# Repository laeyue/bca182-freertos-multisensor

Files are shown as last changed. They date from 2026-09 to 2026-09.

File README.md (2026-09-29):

# FreeRTOS STM32 Room Multisensor

## Project Overview

A simulated STM32F103C8 Blue Pill monitors temperature, relative humidity, ambient brightness, and PIR motion. A rotary encoder selects one measurement on an SSD1306 OLED. A 500 Hz PWM buzzer sounds outside the inclusive 18-30 C temperature range. After 15 seconds without PIR activity, the OLED blanks; new motion restores it. The firmware uses STM32Cube HAL and native FreeRTOS APIs, with no Arduino framework or libraries.

The Blue Pill firmware builds and all 15 host logic tests pass. VS Code Wokwi runs verified DHT22 readings, changing LDR values, all four OLED pages, PIR activity/inactivity, and both encoder page sequences with wraparound. At 33.1 C, the OLED displayed ALARM and the Wokwi buzzer activity icon appeared; a PB8 logic-analyzer capture shows approximately 500 Hz PWM, and a recovery capture shows the output returning low after a normal sample. Independent physical sound level and physical-board behavior have not been measured. See [the verification record](docs/verification.md) for evidence and limits.

## Features

- DHT22 temperature and humidity sampling every 2 seconds, with checksum and timeout handling.
- ADC1 light sampling converted to a relative 0-100% brightness indication. It is not calibrated lux.
- PIR motion detection, ACTIVE/INACTIVE state, and 15 second inactivity timeout.
- Four OLED pages with encoder navigation and wraparound.
- High and low temperature alarm with TIM4 PWM output.
- One-slot queues for current readings and display updates, an event group for activity/alarm state, and a mutex for UART diagnostics.

## Learning Objectives

The project demonstrates periodic scheduling, explicit priorities, task states, queue ownership, event signaling, shared UART protection, modular HAL drivers, host unit tests, and PlatformIO static analysis. [The academic report](docs/laboratory-report.pdf) explains the timing and design trade-offs.

## System Architecture

```mermaid
flowchart LR
  DHT[DHT22 PB12] --> STM[STM32F103C8]
  LDR[LDR AO PA0] --> STM
  PIR[PIR PB13] --> STM
  ENC[Encoder PA1/PA2] --> STM
  STM --> OLED[SSD1306 PB6/PB7]
  STM --> BUZ[Buzzer TIM4 CH3 PB8]
  STM --> UART[USART1 PA9 diagnostics]
```

*Figure 1. Peripheral signals and their MCU pins. The editable Wokwi circuit is [diagram.json](diagram.json). See [the verification record](docs/verification.md) for live simulation observations.*

## FreeRTOS Architecture

```mermaid
flowchart LR
  S[SensorTask] -->|SensorData overwrite| DQ[Display sensor queue] --> D[DisplayTask]
  S -->|SensorData overwrite| AQ[Alarm sensor queue] --> A[AlarmTask]
  M[MotionTask] -->|EVENT_MOTION| E[Event group] --> ST[StateTask]
  ST -->|EVENT_ACTIVE| E
  A -->|EVENT_ALARM| E
  M -->|motion boolean| MQ[Motion display queue] --> D
  I[Encoder EXTI] --> EQ[Encoder queue] --> IN[InputTask]
  IN -->|DisplayMode overwrite| PM[Page queue] --> D
  E --> D
  E --> IN
  E --> A
  S & M & ST & IN & A --> U[UART mutex and USART1]
```

*Figure 2. Queue copies keep independent consumers from stealing updates from one another. The event group carries level state and motion signals.*

## Hardware / Simulated Components

STM32 Blue Pill, DHT22, Wokwi photoresistor module, PIR motion sensor, KY-040 rotary encoder, 128x64 SSD1306 I2C OLED, and piezo buzzer. All sensor modules are connected to 3.3 V in the Wokwi diagram.

## Pin Configuration

| Device | Signal | STM32 pin | Driver |
| --- | --- | --- | --- |
| DHT22 | SDA | PB12 | 5.1 kΩ pull-up to 3.3 V; open-drain start, input-pull-up receive |
| LDR | AO | PA0 | ADC1 channel 0 |
| PIR | OUT | PB13 | GPIO input |
| Encoder | CLK / DT | PA1 / PA2 | EXTI1 / GPIO input |
| OLED | SCL / SDA | PB6 / PB7 | I2C1, address 0x3C |
| Buzzer | + | PB8 | TIM4 channel 3 PWM |
| Diagnostics | TX | PA9 | USART1, 115200 baud |

## Task Design

| Task | Priority | Trigger / period | Blocked condition |
| --- | ---: | --- | --- |
| MotionTask | 3 | Every 50 ms | `vTaskDelayUntil()` |
| InputTask | 3 | Encoder EXTI event | Encoder queue receive |
| StateTask | 3 | Motion event or 100 ms timeout | Event-group wait |
| SensorTask | 2 | Every 2 s | `vTaskDelayUntil()` |
| AlarmTask | 2 | Sensor update or 100 ms timeout | Alarm queue receive |
| DisplayTask | 1 | Sensor/page/motion polling, then 100 ms wait | Sensor queue; ACTIVE event while inactive |

Motion, input, and state response have the shortest latency budget. Sampling and alarm processing tolerate the bounded 2-second DHT interval. OLED transfers are slower and can run at priority 1. Each infinite task loop blocks. `vTaskDelayUntil()` anchors repeated wakeups to a fixed schedule so work duration does not accumulate as drift as it would with a plain relative `vTaskDelay()`.

## Inter-Task Communication

`SensorTask` overwrites separate one-element display and alarm queues with `SensorData {temperature, humidity, lightLevel, dhtValid}`. This prevents a consumer from removing a reading needed by another. `MotionTask` sets `EVENT_MOTION` while PIR is high and sends motion changes to the display queue. `StateTask` consumes and clears the motion event, sets or clears `EVENT_ACTIVE`, and owns the activity state. `AlarmTask` owns `EVENT_ALARM`. `InputTask` receives signed encoder directions from the ISR through an eight-item queue and overwrites the selected page queue.

`serialMutex` protects the shared USART1 transmit peripheral. Sensor, motion, input, state, and alarm tasks can log at the same time; without the mutex, byte streams from separate task calls could interleave and corrupt diagnostic lines. The display alone owns I2C1/OLED; no display mutex is needed.

## State Machine

```mermaid
stateDiagram-v2
  [*] --> ACTIVE
  ACTIVE --> INACTIVE: 15 s since last PIR high
  INACTIVE --> ACTIVE: PIR high
  ACTIVE --> ACTIVE: PIR high refreshes timer
  INACTIVE --> INACTIVE: no motion
```

*Figure 3. State transitions. Sensor sampling continues during INACTIVE so a fresh reading is available after reactivation; OLED rendering and the buzzer stop.*

## Repository Structure

`src/` holds task and HAL code, `include/` public firmware headers, `lib/logic/` pure decision logic, `test/` native Unity tests, `docs/` report and verification records, and `tools/` build/report scripts. `diagram.json` and `wokwi.toml` define the simulator circuit and firmware paths.

## Getting Started

Install PlatformIO Core or the VS Code PlatformIO extension, then install Wokwi for VS Code. Open this folder. STM32CubeF1 contains the FreeRTOS kernel used by `tools/freertos.py`; it compiles only the Cortex-M3 port and heap_4 allocator. No Arduino dependency is required.

## Building the Project

```sh
pio run -e bluepill_f103c8
```

The generated firmware is `.pio/build/bluepill_f103c8/firmware.bin`. Tested with PlatformIO Core 6.2.0 and ST STM32 platform 20.0.0. The production build used 21,620 B flash and 12,060 B static RAM; rerun the command for current totals.

## Running the Wokwi Simulation

Build first, then use **Wokwi: Start Simulator** in VS Code. The circuit is in `diagram.json`; the compiled binary and ELF paths are in `wokwi.toml`. Open the DHT22 sliders, LDR lux control, PIR motion popup, and encoder arrows to exercise the scenarios in `docs/verification.md`. Allow 15 seconds after PIR returns low to test inactivity. The buzzer is driven by TIM4 PWM, not a static GPIO high.

## Unit Testing

```sh
pio test -e native
```

The 15 Unity cases cover all five alarm boundaries, four navigation transitions, four state transitions, and two ADC brightness endpoints. The native target tests pure logic without requiring a physical board.

## Static Code Analysis

```sh
pio check -e bluepill_f103c8
```

The latest run reports 16 low-severity C-style-cast findings and no medium or high findings. The casts come from STM32 HAL register or FreeRTOS macro expansions at the project call sites; see the report for details.

## Functional Verification

[The verification record](docs/verification.md) lists FT-01 through FT-10 with stimuli, expected outcomes and actual observations. DHT22, LDR, OLED pages, PIR active/inactive transitions, both encoder page sequences with wraparound, and the high-temperature alarm's OLED/buzzer response passed in Wokwi. PB8 PWM start/recovery is retained as VCD evidence. Independent physical sound level and physical-board behavior remain unmeasured. Reversible no-delay and high-priority MotionTask faults starved lower-priority sensor output; a short UART mutex-bypass run did not reproduce interleaving. No test is marked PASS based only on compilation.

### Wokwi evidence

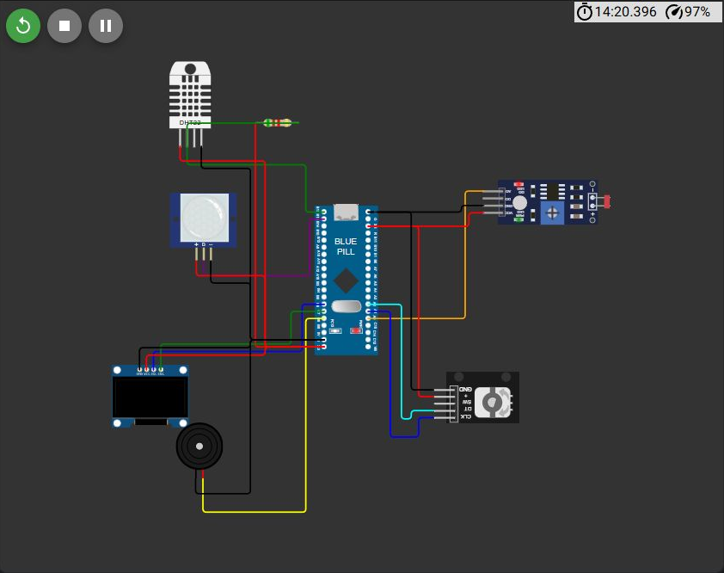
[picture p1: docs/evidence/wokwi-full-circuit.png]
Full Wokwi circuit


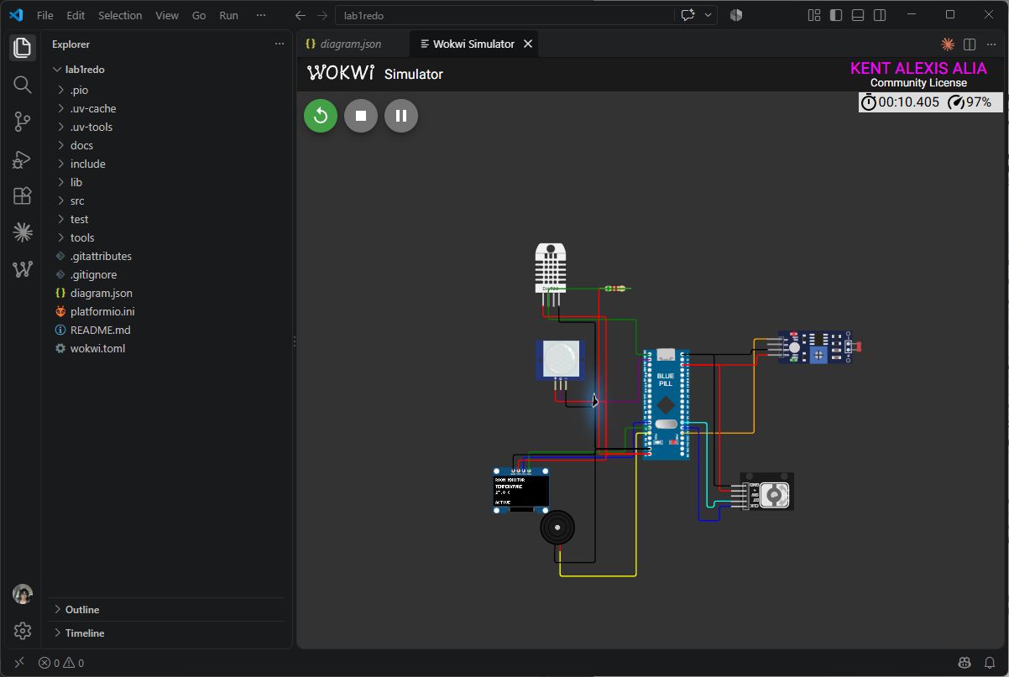
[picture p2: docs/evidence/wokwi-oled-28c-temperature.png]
OLED Temperature page at 27.8 C


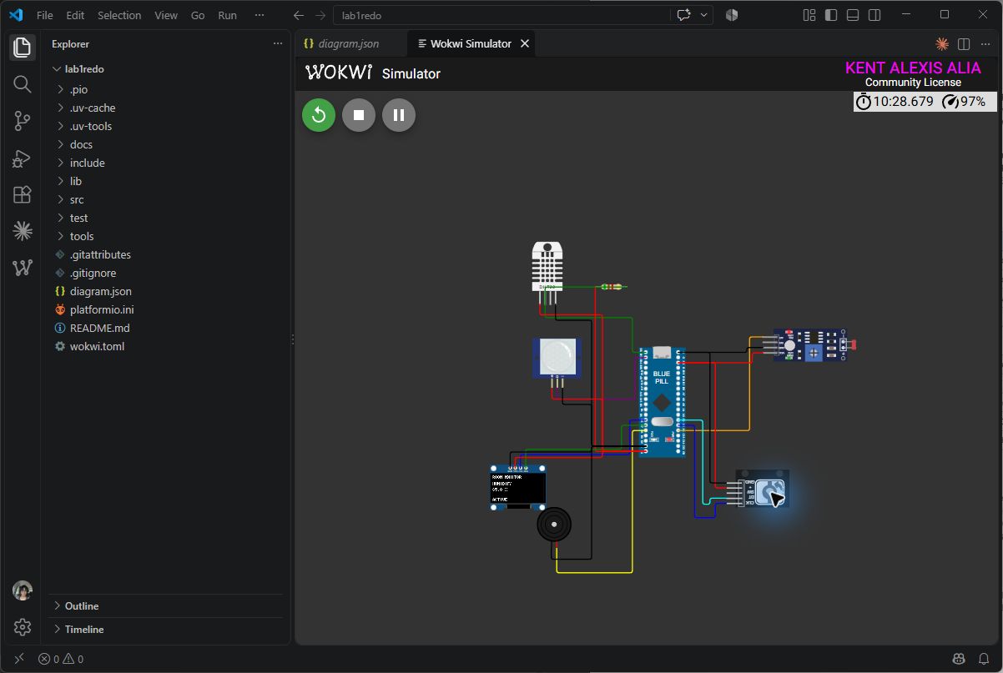
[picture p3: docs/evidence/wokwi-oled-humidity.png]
OLED Humidity page at 65 percent


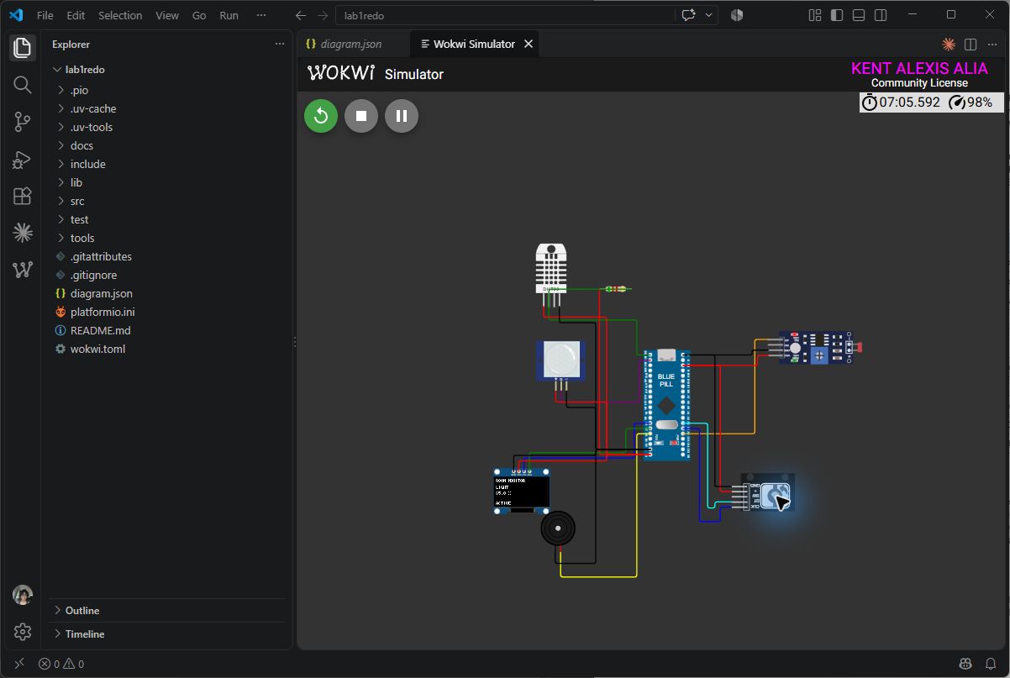
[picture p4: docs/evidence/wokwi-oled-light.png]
OLED Light page


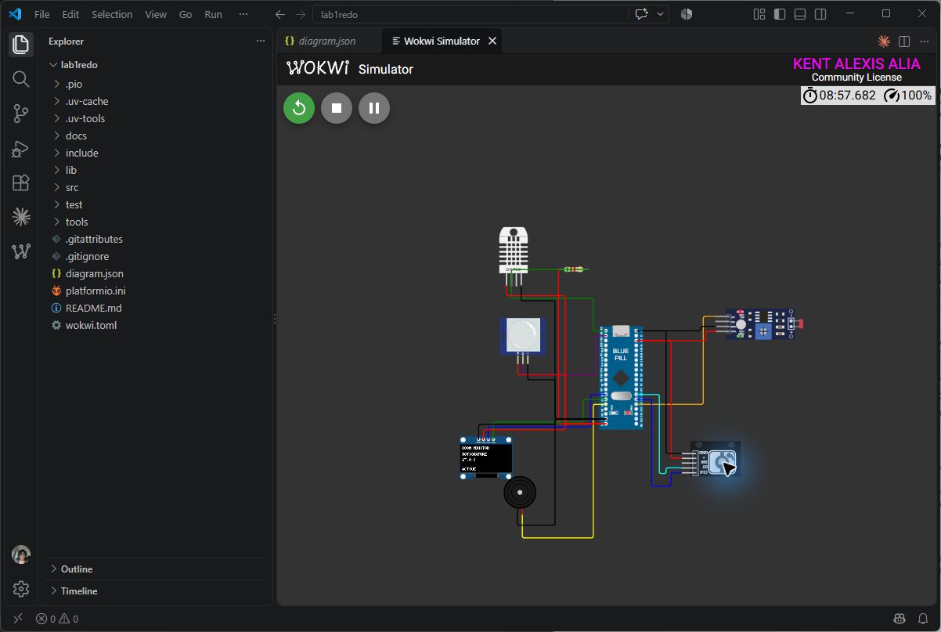
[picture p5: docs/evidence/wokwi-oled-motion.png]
OLED Motion page


[Buzzer high-temperature waveform and recovery](docs/evidence/wokwi-buzzer-alarm-on.vcd) · [PIR high/low trace](docs/evidence/wokwi-pir-cycle.vcd) · [Encoder quadrature trace](docs/evidence/wokwi-input-components.vcd)

## Engineering Decisions

- Two sensor queues give display and alarm independent newest-value mailboxes. A single queue with two consumers would split readings unpredictably.
- The DHT22 transaction samples each data bit 40 us after its rising edge, between the sensor's short zero and long one pulses. The roughly 4 ms transaction runs inside a FreeRTOS critical section, so it temporarily delays lower-priority interrupts; a timer-capture design would scale better on hardware.
- The ADC percentage is inverted because the Wokwi LDR module AO voltage falls as brightness rises. It is a relative indication with no lux claim.
- TIM4 produces an audible 500 Hz square wave; a steady GPIO level would not drive a piezo buzzer properly.
- The alarm is muted in INACTIVE, following the lab's ACTIVE behavior description. Temperature evaluation resumes from current samples when activity returns.

## Limitations

Interactive Wokwi checks cover DHT22 decoding through a 45.8 C input, LDR response, all four OLED pages, task wakeups, PIR high/low and inactivity, both ordered encoder page sequences with wraparound, and the OLED/buzzer high-temperature response. A PB8 VCD proves the buzzer PWM waveform starts at about 500 Hz for a high-temperature sample and stops after a normal sample. No independent physical acoustic level or physical-board behavior has been measured. The no-delay and high-priority fault experiments starved sensor output; the UART mutex-bypass run did not reproduce interleaving. DHT22 sampling masks interrupts for several milliseconds. The inactivity timeout measures from the last observed PIR-high sample; the normal PIR simulation hold is five seconds. No environmental sensor calibration is attempted. DHT errors suppress the alarm rather than sounding a fault tone. Wokwi circuitry does not establish electrical suitability for physical hardware.

## Future Improvements

Capture DHT pulses with a hardware timer input capture, persist configuration in nonvolatile storage, add explicit sensor-fault indication, and measure worst-case task latency and stack high-water marks in Wokwi or on hardware.

## References and Acknowledgments

- [PlatformIO STM32Cube framework documentation](https://docs.platformio.org/en/stable/frameworks/stm32cube.html)
- [Wokwi STM32 Blue Pill support](https://docs.wokwi.com/parts/board-stm32-bluepill)
- [Wokwi simulator configuration](https://docs.wokwi.com/vscode/project-config)
- [Wokwi LDR module behavior](https://docs.wokwi.com/parts/wokwi-photoresistor-sensor)
- BCA182 Laboratory Activity 1, Mindanao State University - Iligan Institute of Technology, September 2026.

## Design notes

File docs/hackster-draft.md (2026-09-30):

# Hackster.io project draft

**Publication state:** Draft prepared; not published.

## Listing details

- **Project name:** Real-Time FreeRTOS Room Multisensor
- **Short description:** An STM32 Blue Pill room monitor built with six FreeRTOS tasks, a DHT22, LDR, PIR sensor, rotary encoder, SSD1306 OLED, and PWM buzzer.
- **Repository:** https://github.com/laeyue/bca182-freertos-multisensor
- **Course attribution:** BCA182, Mindanao State University - Iligan Institute of Technology (MSU-IIT)
- **Team / collaborator field:** Add Prof. Paul Rodolf P. Castor using the matching Hackster profile, as required by the laboratory handout.
- **Tags:** FreeRTOS, STM32, embedded, sensors, Wokwi, PlatformIO
- **License:** The repository does not currently declare a license. Hackster permits publishing without an open-source license; if one is selected, add a matching `LICENSE` file to the repository first.

## Hackster Builder Checklist

The article text below is prepared, but this file is not a Hackster project page. Before publishing, complete the corresponding builder fields and wait until Hackster reports the project as 100% complete:

- Choose a crisp, high-resolution cover image of the finished project. The current simulator and circuit screenshots are evidence images, not a polished cover image.
- Select an accurate difficulty and build time.
- Choose up to three project categories.
- Add the hardware below to Hackster's **Things** list, selecting the matching platform and component entries. Keep software tools in the tools section.
- Add Prof. Paul Rodolf P. Castor as a team member / collaborator using the matching Hackster profile.
- Review the story preview, links, image quality, and publication settings.

The license is optional on Hackster. Decide whether to license the source before publication; do not select a license that does not match the repository.

## Project Overview

This project monitors simulated room temperature, humidity, relative brightness, and motion with an STM32F103C8 Blue Pill. A KY-040 rotary encoder selects one of four pages on an SSD1306 OLED. A 500 Hz buzzer output indicates temperatures outside the 18–30 °C range. After 15 seconds without motion, the display blanks; PIR activity restores the active display.

The project was built for BCA182 Laboratory Activity 1 to demonstrate FreeRTOS task scheduling, inter-task communication, periodic work, and state management on an STM32 target.

## Components and Tools

| Hardware component | Quantity | Use |
| --- | ---: | --- |
| STM32F103C8 Blue Pill | 1 | Main controller |
| DHT22 temperature and humidity sensor | 1 | Temperature and humidity input |
| 5.1 kOhm resistor | 1 | DHT22 data pull-up |
| Photoresistor module (LDR) | 1 | Relative light input |
| PIR motion sensor | 1 | Motion input |
| KY-040 rotary encoder | 1 | Display-page selection |
| SSD1306 I2C OLED | 1 | Measurement and state display |
| Piezo buzzer | 1 | Temperature alarm output |

**Software and tools:** PlatformIO, STM32Cube HAL, FreeRTOS, Unity, and Wokwi.

The full circuit and pin assignment are in the public repository. The circuit uses PB12 for DHT22 data with a 5.1 kOhm pull-up, PA0 for LDR analog output, PB13 for PIR output, PA1/PA2 for encoder CLK/DT, PB6/PB7 for I2C1 OLED, PB8 for TIM4 buzzer PWM, and PA9 for USART1 logging.

Wokwi circuit

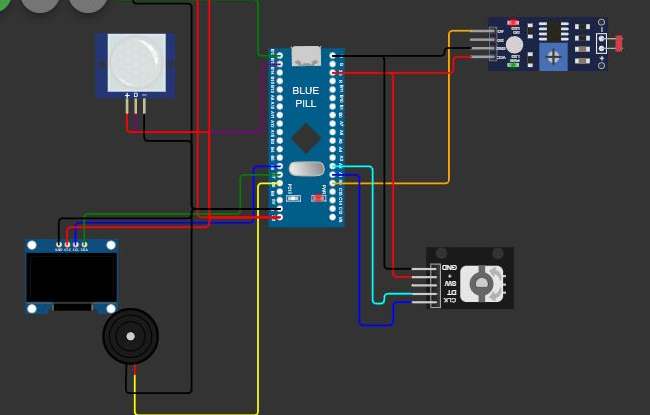
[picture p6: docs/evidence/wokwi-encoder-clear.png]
STM32 Blue Pill, KY-040 encoder, and surrounding wiring


_Wokwi close-up of the STM32 Blue Pill, KY-040 rotary encoder, and surrounding sensor wiring._

## FreeRTOS Architecture

Six tasks divide the work: MotionTask reads PIR state, InputTask handles encoder steps, StateTask owns ACTIVE/INACTIVE state, SensorTask samples DHT22 and LDR, AlarmTask controls the buzzer, and DisplayTask owns the OLED. SensorTask writes the newest sensor data to separate one-item queues for DisplayTask and AlarmTask. The state and alarm event bits live in an event group. A mutex serializes USART1 messages.

The sensor task uses `vTaskDelayUntil()` with a two-second period. The 15-second inactivity timeout is handled by StateTask. Each task blocks on a queue, event, or timed delay between work.

## How It Works

The DHT22 driver releases PB12 into input-pull-up mode and samples each data bit 40 microseconds after its rising edge. This timing separates the sensor's short zero pulse from its longer one pulse. The driver validates the five-byte checksum before publishing a reading. The LDR module is reported as relative brightness, not calibrated lux. Encoder direction is decoded from CLK and DT transitions. DisplayTask renders one selected page. TIM4 channel 3 generates the buzzer waveform at about 500 Hz.

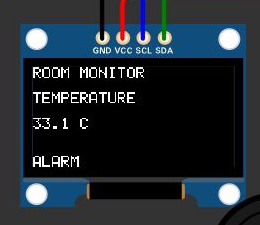
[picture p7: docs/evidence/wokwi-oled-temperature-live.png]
Temperature page


_Live Wokwi OLED view at 33.1 °C with the over-temperature alarm active._

Humidity page

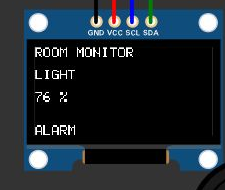
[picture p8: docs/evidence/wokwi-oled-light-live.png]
Light page


_The Light page shows a 76% relative-light reading from the Wokwi photoresistor._

Motion page

## Reproducing the Wokwi Demonstration

1. Clone the [GitHub repository](https://github.com/laeyue/bca182-freertos-multisensor) and open it in VS Code with PlatformIO and Wokwi for VS Code installed.
2. Build the STM32 target with `pio run -e bluepill_f103c8`.
3. Start **Wokwi: Start Simulator**. The circuit is defined in `diagram.json` and the firmware paths are in `wokwi.toml`.
4. Change the DHT22 and photoresistor controls, rotate the encoder in both directions, and trigger the PIR. The [verification record](https://github.com/laeyue/bca182-freertos-multisensor/blob/main/docs/verification.md) lists the observed results and evidence for each functional test.

The Wokwi simulation is the verified target for this project. A physical STM32 board and independent buzzer sound-level measurement were not tested.

## Testing and Verification

The firmware builds for `bluepill_f103c8`. All 15 native Unity tests pass for alarm thresholds, page navigation logic, activity-state transitions, and brightness conversion. PlatformIO static analysis reported zero high and zero medium findings, with 16 low C-style-cast findings at STM32 HAL or FreeRTOS macro call sites.

Live VS Code Wokwi runs showed checksum-valid DHT22 readings, changing LDR output, all four OLED pages, PIR ACTIVE/INACTIVE transitions, and page-change logs for both encoder directions. On 2026-09-30, the full clockwise sequence (Temperature -> Humidity -> Light -> Motion -> Temperature) and reverse sequence (Temperature -> Motion -> Light -> Humidity -> Temperature) were observed while ACTIVE. At 33.1 °C / 66.0%, the OLED showed ALARM and the Wokwi buzzer activity icon appeared; the retained PB8 trace measures about 500 Hz at 50% duty cycle, with a recovery trace returning low after a normal-temperature sample. These are simulator results; no independent physical sound-level measurement or physical-board validation has been made. The test-only PIR hold was restored to its normal five-second value after the run.

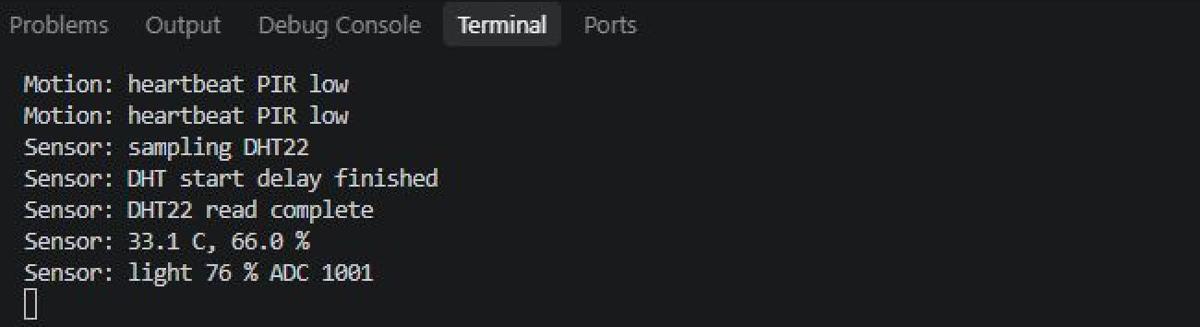
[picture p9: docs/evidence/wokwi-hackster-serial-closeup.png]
Wokwi serial logs from a sensor run


_The serial output records PIR heartbeats, the completed DHT22 read, and the photoresistor ADC reading._

The Wokwi functional checks for encoder wraparound and the high-temperature alarm passed. The independent physical sound level remains unmeasured, and the design has not been validated on physical hardware.

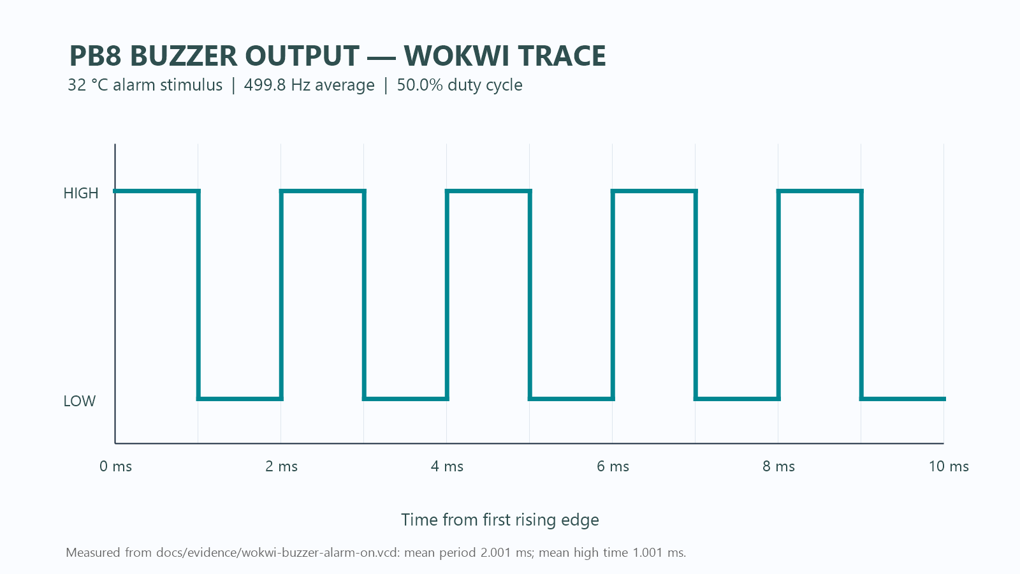
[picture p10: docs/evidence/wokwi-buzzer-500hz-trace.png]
Measured PB8 PWM waveform


_PB8 trace from the 32 °C Wokwi alarm run: 499.8 Hz average and 50.0% duty cycle, measured from the retained VCD capture._

Reversible fault experiments showed that removing MotionTask's blocking delay or raising its priority suppressed sensor output during the observed runs. Bypassing the UART mutex did not reproduce visible line interleaving in the short capture. These are observations from the simulator; they do not replace testing with physical hardware.

The full [functional verification record](https://github.com/laeyue/bca182-freertos-multisensor/blob/main/docs/verification.md) links the screenshots and VCD traces and lists these limits. The public [source repository](https://github.com/laeyue/bca182-freertos-multisensor) includes the circuit, firmware, report, and evidence.

## Challenges and Lessons Learned

A single sensor queue with two consumers would split updates between the display and alarm tasks, so the firmware uses separate one-item mailboxes. The DHT22 needs microsecond timing, and the bit-banged critical section trades interrupt latency for a simpler driver. A steady GPIO level cannot drive a piezo tone; the buzzer needs timer PWM.

## Limitations and Future Improvements

The design has not been validated on a physical board, and no independent acoustic level was measured. Future work could add timer input capture for DHT pulses, calibrated light measurements, measured task latency, and a sensor fault alarm.

## References

BCA182 Laboratory Activity 1 (MSU-IIT, 2026); Aosong AM2302 Technical Manual; STM32CubeF1 documentation and FreeRTOS kernel; PlatformIO STM32Cube documentation; Wokwi component documentation.

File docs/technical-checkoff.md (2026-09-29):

# Technical checkoff notes

Use these notes to explain the design in your own words. The source and actual simulator behavior are the final authority.

1. **Why SensorTask?** DHT22 and ADC acquisition have a 2-second periodic deadline independent of display transfers or encoder events.
2. **Why these priorities?** Motion, encoder and state handling need short response latency (priority 3); sampling and alarm can tolerate the 2-second update cadence (2); the OLED is slower and less urgent (1).
3. **Why `vTaskDelayUntil()`?** It schedules from the previous planned wake time, avoiding cumulative execution-time drift.
4. **What happens during a delay?** The task is Blocked and uses no CPU. At the wake tick it becomes Ready; the scheduler selects it when eligible.
5. **What crosses the sensor queues?** A copied `SensorData`: temperature, humidity, relative light percent and DHT validity.
6. **Why two queues?** DisplayTask and AlarmTask each need the newest sample. Consuming from one shared queue would make one task steal the other's update.
7. **What does the mutex protect?** The shared USART1 transmit operation used by five tasks' diagnostic log calls.
8. **What race can occur?** A task switch during UART output can mix bytes from two messages unless each write holds the mutex.
9. **What are event bits?** MotionTask pulses EVENT_MOTION; StateTask owns EVENT_ACTIVE; AlarmTask owns EVENT_ALARM. Display, input and alarm tasks read relevant level bits.
10. **Who owns the OLED?** DisplayTask alone, so I2C frame writes cannot interleave.
11. **What if a high-priority task never blocks?** It can keep lower-priority sensor, alarm and display tasks Ready indefinitely, causing starvation.
12. **Ready versus Blocked?** Ready can run once selected; Blocked waits for a time, message or event.
13. **What do unit tests verify?** Alarm thresholds including exact boundaries, encoder wraparound, activity-state transitions, and brightness endpoint conversion. A live Wokwi run while ACTIVE showed the clockwise sequence Temperature -> Humidity -> Light -> Motion -> Temperature and the reverse sequence Temperature -> Motion -> Light -> Humidity -> Temperature, with page-change logs.
14. **What did static analysis find?** `pio check` reported 16 low-severity C-style cast findings at HAL/FreeRTOS macro call sites, with no medium or high findings.
15. **What did the buzzer check verify?** At 32 C, PB8 produced approximately 500 Hz PWM; after a 23.5 C sample, PB8 stayed low. In a live 33.1 C Wokwi run, the OLED displayed ALARM and the simulator showed the buzzer activity icon. No independent physical sound-level measurement was made.
16. **What did the fault experiments show?** Removing MotionTask's 50 ms delay caused repeating heartbeats and suppressed sensor output; setting priority 4 with a 1 ms delay also starved sensor output. Bypassing the UART mutex did not visibly corrupt output in the short run, so that race was not reproduced.
17. **What changes on hardware?** Voltage levels, pull-ups, buzzer drive, power supply, sensor calibration, timing margins and EMI need electrical validation. Wokwi models do not establish those properties.

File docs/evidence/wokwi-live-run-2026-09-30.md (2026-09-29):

# Wokwi live verification run — 2026-09-30

This run was performed in the Wokwi VS Code simulator. It records the live
observations made while driving the circuit through the simulator controls.
No screenshot was retained from this session.

## Test setup

- DHT22: 33.1 C and 66.0% humidity for the alarm check.
- PIR `delayTime`: temporarily set to 86,400 seconds because the Wokwi
  simulator fast-forwarded simulated time between manual UI actions.
- After the run, `diagram.json` was restored to DHT22 24 C / 40% and PIR
  `delayTime` 5 seconds.

## Observed results

- Serial output repeatedly showed `Sensor: sampling DHT22`,
  `Sensor: DHT start delay finished`, `Sensor: DHT22 read complete`,
  `Sensor: 33.1 C, 66.0 %`, `Sensor: light 76 % ADC 1001`, and
  `Motion: heartbeat PIR high`.
- While ACTIVE, clockwise encoder steps showed Temperature -> Humidity ->
  Light -> Motion -> Temperature. Counterclockwise steps showed Temperature
  -> Motion -> Light -> Humidity -> Temperature. The serial monitor showed
  `Input: display page changed` during navigation.
- At 33.1 C, the OLED Temperature page showed `ALARM`; Wokwi displayed the
  buzzer activity icon. The retained [PB8 alarm waveform](wokwi-buzzer-alarm-on.vcd)
  separately shows approximately 500 Hz PWM at the high-temperature setting,
  and the [recovery waveform](wokwi-buzzer-recovery.vcd) shows PB8 returning
  low after a normal-temperature sample.

These observations verify the simulated alarm path and both encoder page
sequences. They do not measure physical buzzer loudness or validate the circuit
on a physical board.

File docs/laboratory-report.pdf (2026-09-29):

BCA182 - Laboratory Activity 1 | Page 1

# BCA182 Laboratory Activity 1

Real-Time Multisensor Room Monitoring System

Name: Kent Alexis Alia | Section: B182 | Date: 9/30/26

Status: firmware build, 15 native tests, and static analysis passed. Wokwi verified DHT22 and LDR readings, all four OLED pages, PIR activity/inactivity, clockwise and counterclockwise page wrap, and the high-temperature alarm display/buzzer response. The retained PB8 trace shows PWM start and recovery. Physical sound level and physical-board behavior were not measured. Two reversible scheduling faults starved sensor output; the UART mutex-bypass trial did not reproduce interleaving.

## 1. Problem and Requirements

The device monitors temperature, humidity, relative brightness and motion with a simulated STM32F103C8. A rotary encoder selects one of four OLED pages. A PWM buzzer indicates temperatures strictly below 18 C or strictly above 30 C. A 15-second no-motion interval enters INACTIVE; PIR activity restores ACTIVE. The architecture must use multiple FreeRTOS tasks, queues, a mutex, an event mechanism and periodic execution.

The laboratory handout contains a contradictory statement that the configuration must identify ESP-IDF, adjacent to a STM32Cube example. The STM32 Blue Pill target and all surrounding framework requirements specify STM32Cube, so this project uses framework = stm32cube. Wokwi-supported ADC1, I2C1, USART1, EXTI and TIM2/TIM4 features are used; no Arduino abstraction is included.

## 2. System Architecture and Design

Subsystem | Device / pins | Responsibilities
Sensing | DHT22 PB12; LDR AO PA0 | DHT pulse decoding and checksum; ADC1 relative brightness
Presence / input | PIR PB13; encoder PA1/PA2 | Motion event and page navigation
Output | SSD1306 PB6/PB7; buzzer PB8 | I2C display and TIM4 500 Hz PWM alarm
Diagnostics | USART1 PA9 | Serialized task log output

StateTask owns the ACTIVE/INACTIVE state. On each PIR-high observation it refreshes lastMotion. When elapsed time since that observation reaches 15,000 ms, it clears EVENT_ACTIVE. A new EVENT_MOTION restores ACTIVE. DisplayTask turns the OLED off and blocks on EVENT_ACTIVE while inactive. AlarmTask mutes the buzzer in that state; sensor sampling continues to keep readings fresh.

## 3. FreeRTOS Architecture

Task | Priority | Trigger / period | IPC | Typical blocked condition
MotionTask | 3 | 50 ms | EVENT_MOTION; motion queue | DelayUntil
InputTask | 3 | Encoder EXTI | Encoder and page queues | Queue receive
StateTask | 3 | Motion / 100 ms | Event group | Event wait
SensorTask | 2 | 2 s | Display + alarm queues | DelayUntil
AlarmTask | 2 | Sensor / 100 ms | Alarm queue; EVENT_ALARM | Queue receive
DisplayTask | 1 | Update / 100 ms | Sensor, page, motion queues | Queue or ACTIVE wait

Motion, encoder and state transitions have the tightest response budgets and use priority 3. Two-second sensor sampling and alarm evaluation tolerate priority 2. OLED transfers tolerate additional latency and use priority 1. All loops block or wait, avoiding a continuously ready high-priority task. The only short busy interval is the DHT timing transaction inside a critical section.

SensorTask overwrites two separate single-item SensorData queues. DisplayTask and AlarmTask must both see the newest reading; a single destructive-consumption queue would distribute, rather than broadcast, messages. InputTask consumes signed encoder steps from an ISR queue and writes the current DisplayMode to a mailbox queue. MotionTask sends a separate motion boolean to DisplayTask because the PIR and DHT/ADC have distinct task owners.

EVENT_MOTION is set by MotionTask on PIR-high samples and consumed/cleared by StateTask. EVENT_ACTIVE is set or cleared only by StateTask and read by display, input and alarm tasks. EVENT_ALARM is set or cleared only by AlarmTask and read by DisplayTask. These bits represent actual application events and level state, rather than unused placeholders.

The mutex protects USART1 transmission. SensorTask, MotionTask, InputTask, StateTask and AlarmTask may log concurrently. Without serialization, a task switch between bytes could interleave diagnostic lines. The OLED is single-owner and does not require a mutex.

A Running task currently uses the CPU. A Ready task can run but waits for scheduler selection. A Blocked task waits for time, a queue or an event and consumes no CPU. This application deliberately uses Blocked states. No task is Suspended or Deleted during normal operation; those states mean respectively excluded from scheduling until resumed, and removed with resources eligible for reclamation.

vTaskDelayUntil() computes each wake time from the previous scheduled wake, keeping nominal sensor samples 2 seconds apart. vTaskDelay(2000) would add the execution time of each DHT/ADC cycle to every period, creating cumulative drift.

## 4. Implementation

board.cpp initializes HSI/PLL at 64 MHz, GPIO, ADC1, I2C1, USART1 and two timers. TIM2/DWT timing supports the DHT22 transaction. SensorTask pulls its open-drain data pin low for 2 ms, then samples each data bit 40 us after its rising edge inside a FreeRTOS critical section. This midpoint separates the AM2302 zero pulse (26-28 us high) from its approximately 70 us one pulse. The task validates the checksum and converts tenths to Celsius and relative humidity. Invalid DHT data is shown as SENSOR ERROR and suppresses a false temperature alarm.

The LDR module's AO voltage decreases as simulated illumination increases. The firmware maps the 12-bit ADC code inversely into an approximate 0-100% relative brightness scale; it does not infer calibrated lux. The encoder's CLK falling edge is handled by EXTI1; its DT level determines direction. DisplayTask alone builds a 1 KB page buffer and writes it over I2C1 to the SSD1306. TIM4 channel 3 generates a 500 Hz, 50% duty cycle buzzer waveform.

## 5. Verification and Testing

The bluepill_f103c8 STM32Cube firmware build used 21,620 of 65,536 flash bytes and 12,060 of 20,480 static RAM bytes. All 15 native Unity tests passed: five alarm thresholds, four navigation transitions, four state transitions and two brightness endpoints. Static analysis reported zero high, zero medium and 16 low C-style cast findings at STM32 HAL or FreeRTOS macro call sites. These checks do not test HAL timing or wiring.

Functional tests | Evidence state
DHT22 acquisition | Checksum-valid Wokwi serial reads at 24 C / 40%, 27.8 C / 65%, 32 C / 65%, and 45.8 C / 65%; revised 40 us midpoint decoder
FT-01 to FT-03: OLED sensor pages | PASS: Temperature 27.8 C, Humidity 65.0%, and Light page rendered; corresponding screenshots are in docs/evidence/
FT-04 to FT-05: encoder navigation | PASS: while ACTIVE, Wokwi showed Temperature -> Humidity -> Light -> Motion -> Temperature clockwise and the reverse sequence counterclockwise, with page-change logs
FT-06 to FT-07: buzzer thresholds | PASS in Wokwi: at 33.1 C / 66%, OLED showed ALARM and the simulator buzzer activity icon appeared; retained PB8 trace is about 500 Hz and recovery trace returns low. Physical sound level was not measured
FT-08 to FT-10: motion/inactivity | PASS: PIR high produced Motion: detected and State: ACTIVE; the earlier timeout run showed State: INACTIVE and a blank OLED
Fault experiments | No delay and high-priority MotionTask variants suppressed sensor output; bypassing the UART mutex did not produce visible interleaving in the short run

Separate OLED screenshots show all four pages; LDR output changed from 76% at 501 lux to 97% at 13,183 lux. Checksum-valid DHT samples ranged from 24 C to 45.8 C. At 32 C, the PB8 VCD shows 4,096 transitions at about 500 Hz; after a valid 23.5 C sample it stayed low. PIR activation logged ACTIVE, and a separate timeout test logged INACTIVE with the OLED blank. On 2026-09-30, a live VS Code Wokwi run showed the clockwise page sequence Temperature -> Humidity -> Light -> Motion -> Temperature and the reverse sequence, with InputTask page-change logs. At 33.1 C / 66.0%, serial showed a valid sensor sample, the OLED displayed ALARM, and the Wokwi buzzer activity icon appeared. The temporary test DHT and extended PIR hold settings were restored to defaults after the run. No new screenshot was retained; the text run record and retained traces are in docs/evidence/. Physical sound level and physical-board behavior were not measured. No-delay and high-priority faults suppressed sensor output; the UART mutex-bypass test showed no visible interleaving.

## 6. Static Code Analysis

The latest pio check run passed with zero high, zero medium and 16 low style messages. These C-style-cast reports point to STM32 HAL register or FreeRTOS macro expansions at board.cpp, input.cpp and main.cpp call sites; no high or medium finding was reported.

Finding | Location / cause | Resolution
C-style casts (16) | HAL / FreeRTOS macro expansion | Retained; low-severity macro style

## 7. Engineering Discussion

The STM32F103C8 has only 20 KB RAM. A one-kilobyte static OLED framebuffer, one-slot mailboxes and small task stacks keep static RAM below 60% in the measured build. A queue-per-consumer costs some RAM but avoids lost sensor updates. DHT pulse capture disables interrupts for roughly 4 ms, which can disturb precise task latency; timer input capture would be preferable for a production design. The alarm is muted in INACTIVE according to the stated ACTIVE behavior, but a safety-critical monitor could choose to keep it active instead.

The evidence includes Wokwi checks for DHT22 values through 45.8 C, LDR response, four OLED pages, both encoder page sequences with wraparound, PIR active/inactive transitions, and the 500 Hz buzzer PWM start and recovery, in addition to build, unit tests and static analysis. The 2026-09-30 live run also showed the high-temperature ALARM page and the Wokwi buzzer activity icon. The no-delay and high-priority MotionTask faults suppressed sensor output. The UART mutex-bypass trial showed no visible interleaving, so that race was not reproduced. Physical deployment still needs voltage, pull-up, EMI, timing, acoustic and thermal validation. Sensor calibration and fault-tolerant alarming are outside this laboratory prototype.

## 8. Requirements Traceability

Req. | Implementation | Verification
FR-01 | SensorTask DHT temperature | Valid Wokwi readings observed through 45.8 C; OLED FT-01 pass at 27.8 C
FR-02 | SensorTask DHT humidity | Wokwi serial value and OLED FT-02 pass at 65.0%
FR-03 | SensorTask ADC1 relative light | Changed Wokwi ADC readings and OLED FT-03 pass
FR-04 | MotionTask PIR | PASS: motion detected and ACTIVE serial logs observed; high/low trace captured
FR-05 | DisplayTask OLED | Temperature, Humidity, Light and Motion pages rendered in Wokwi
FR-06 | InputTask encoder | PASS: Wokwi showed ordered page navigation and wrap in both directions while ACTIVE
FR-07 | AlarmTask PWM buzzer | PASS for PB8 PWM start and stop: about 500 Hz at 32 C, low after 23.5 C; no acoustic measurement
FR-08 | StateTask ACTIVE/INACTIVE | PASS: ACTIVE and INACTIVE state logs observed with OLED off/on behavior
FR-09 | StateTask 15 s timeout | Unit timeout and Wokwi INACTIVE observation; FT-09 pass
FR-10 | StateTask PIR reactivation | PASS: PIR trigger after inactivity produced Motion: detected and State: ACTIVE

## 9. Conclusion

The project demonstrates a modular STM32Cube/FreeRTOS design with separate task responsibilities, intentional IPC, time-based state management and deterministic host tests. Wokwi verified DHT22 acquisition up to 45.8 C, LDR response, all four OLED pages, PIR activity/inactivity, both ordered encoder page sequences with wraparound, and the high-temperature OLED ALARM/buzzer response. The fault experiments reproduced starvation when a frequent MotionTask did not block or ran at excessive priority; the short UART mutex-bypass trial did not reproduce a corrupted line. Physical sound level and physical-board behavior remain unmeasured.

## References

BCA182 Laboratory Activity 1 (MSU-IIT, 2026); Aosong AM2302 Technical Manual; PlatformIO STM32Cube documentation; Wokwi STM32 Blue Pill documentation; FreeRTOS kernel source distributed in STM32CubeF1.

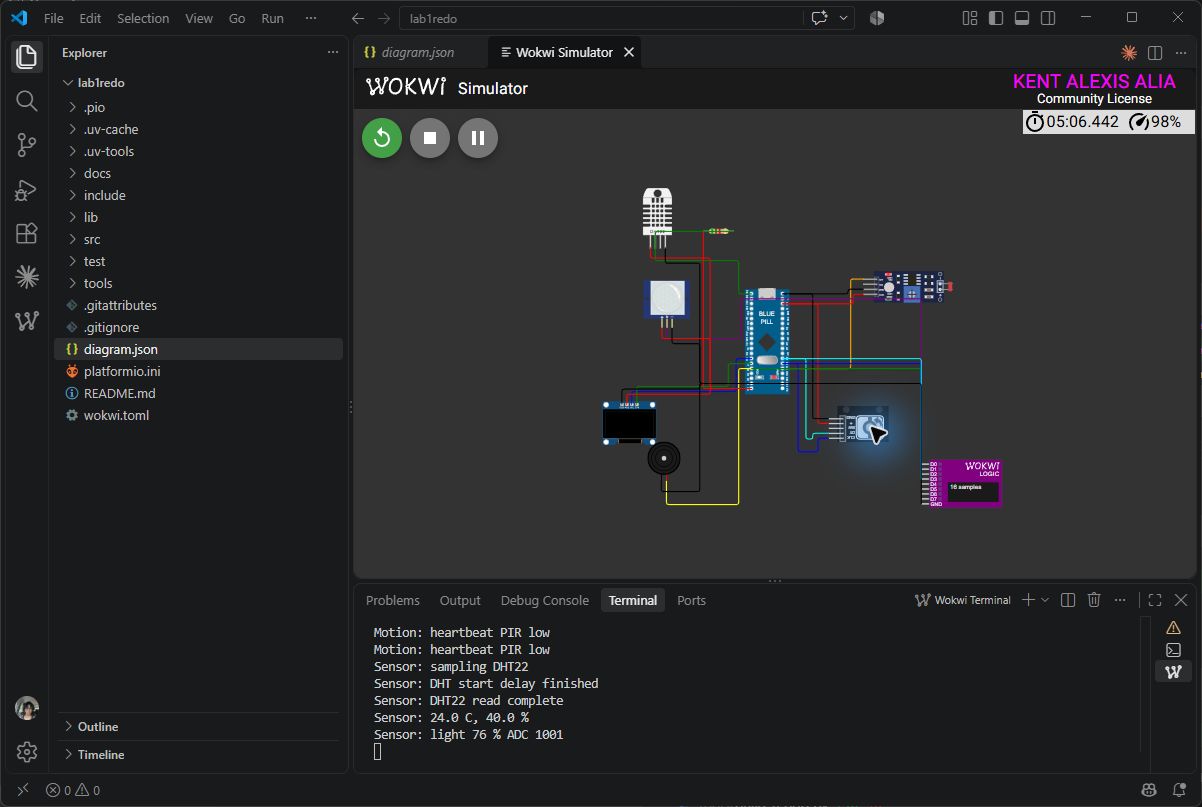
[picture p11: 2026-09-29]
docs/evidence/wokwi-encoder-pulses.png

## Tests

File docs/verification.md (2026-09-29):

# Wokwi functional verification record

Build with `pio run -e bluepill_f103c8`, start Wokwi for VS Code, and record the **observed** OLED/serial/buzzer behavior before assigning PASS or FAIL. Native tests and static analysis do not exercise Wokwi peripherals, so interactive observations are recorded separately below.

## Startup wakeup diagnosis

The original Wokwi run reached `Scheduler running` and
`Sensor: sampling DHT22`, then omitted the DHT start-delay completion and
MotionTask heartbeat. Those messages precede DHT bit decoding, so sensor data
alone could not explain that stall. After the SysTick and PendSV port changes,
a clean Wokwi run reached `Sensor: DHT start delay finished`,
`Sensor: DHT22 read complete`, repeated sensor samples, and MotionTask
heartbeats. One manual restart attempt did not show progress; a rebuild/reload
then produced repeated wakeups. The latest clean image also showed continued
sampling after reload. The startup symptom is considered cleared in the
observed reload run, though restart behavior should be monitored in later runs.

On 2026-09-30, a follow-up live run in VS Code Wokwi again progressed beyond
the earlier stall. The visible serial output included `Sensor: sampling DHT22`,
`Sensor: DHT start delay finished`, `Sensor: DHT22 read complete`,
`Sensor: 33.1 C, 66.0 %`, `Sensor: light 76 % ADC 1001`, and recurring
`Motion: heartbeat PIR high` messages. While ACTIVE, the OLED showed the
clockwise page sequence Temperature -> Humidity -> Light -> Motion ->
Temperature and the reverse sequence Temperature -> Motion -> Light ->
Humidity -> Temperature. `Input: display page changed` appeared as the pages
advanced. At 33.1 C the Temperature page displayed `ALARM`, and the Wokwi
buzzer activity icon was visible. A temporary test setup used DHT22 33.1 C /
66.0% and a 86,400-second PIR hold because Wokwi fast-forwarded simulated time
between manual interactions. The committed diagram was restored to 24 C / 40%
and the normal five-second PIR hold after the run. This live observation was
not saved as a new image; the earlier retained production-run screenshots and
the new text run record are linked below. No independent physical acoustic
measurement was made.

### Static ELF audit

The production ELF places the vector table at `0x08000000`. Its SVC, PendSV,
and SysTick entries resolve to `SVC_Handler` (`0x08001810`),
`PendSV_Handler` (`0x08001870`), and `SysTick_Handler` (`0x08003ef8`). The
disassembly also shows `vTaskDelay()` setting `PENDSVSET`,
`xTaskIncrementTick()` incrementing the tick and moving expired tasks from the
delayed list to the ready list, and PendSV calling `vTaskSwitchContext()`.
These checks rule out a missing or weak exception-vector mapping in the linked
image. They do not show whether PendSV runs in Wokwi or whether UART output is
being lost after the delay.

## DHT22 bus and timing fixes

The failed read was waiting for the sensor's response-high edge. PB12 stayed in
output open-drain mode after the host released the bus, so the STM32F1 internal
pull-up was not enabled. The [AM2302 datasheet](https://files.seeedstudio.com/wiki/Grove-Temperature_and_Humidity_Sensor_Pro/res/AM2302-EN.pdf)
recommends an approximately 5.1 kΩ external pull-up and releasing the bus by
switching the MCU pin to input. The diagram now includes that resistor, and the
driver switches PB12 to input-pull-up for receive and waits two seconds after
power-up before the first sample.

The initial receive implementation classified bits by measuring the high pulse
between two polled GPIO edges and testing whether the result exceeded 50 us.
Because both edge timestamps include polling delay, that decision could move
near the zero/one boundary and produce bad bytes/checksums. The revised decoder
samples the bus 40 us after the rising edge, between the AM2302's short zero
pulse (26-28 us) and long one pulse (about 70 us), then waits for the falling
edge before starting the next bit. A live VS Code Wokwi run produced repeated
checksum-valid `24.0 C, 40.0 %` and `32.0 C, 65.0 %` readings after changing the
DHT controls. No checksum-failure diagnostic appeared in the observed samples.
The timing is based on the [Aosong AM2302 technical manual](https://www.aosong.com/uploadfiles/2025/04/20250417105409216.pdf).

## Buzzer output fix and verification

The high-temperature test initially showed that TIM4 was running while PB8
produced no PWM. The PB8 alternate-function push-pull setup left
`GPIO_InitTypeDef.Speed` at zero; on the STM32F1 this selects the input mode,
so the timer output never reached the pin. `boardInit()` now configures PB8 at
`GPIO_SPEED_FREQ_HIGH` before starting TIM4 channel 3.

With the production firmware, the DHT22 was set to 32.0 C / 65.0%. The live
serial monitor showed that checksum-valid reading, and the logic-analyzer
capture at PB8 contains 4,096 transitions. The measured mean period is about
2.000 ms (approximately 500 Hz) with roughly 50% duty cycle. This proves the
MCU output is producing the configured alarm waveform; it does not constitute
an independent acoustic measurement. The Wokwi buzzer is connected to PB8.

For recovery, the DHT22 was changed live to 23.5 C / 65.0%. The next valid
sample appeared in the serial log, and the recovery VCD ends with PB8 low and
remaining low after the normal-temperature sample. The screenshot and VCD are
stored as `evidence/wokwi-buzzer-recovery.png` and
`evidence/wokwi-buzzer-recovery.vcd`. The no-PWM screenshot records the
pre-fix symptom.

| ID | Stimulus | Expected result | Actual observation | Result |
| --- | --- | --- | --- | --- |
| FT-01 | Set DHT22 to 28 C, select Temperature | OLED shows about 28.0 C within 2 s | DHT control was set to 27.8 C; the Temperature page showed 27.8 C and ACTIVE | PASS |
| FT-02 | Set DHT22 to 65%, select Humidity | OLED shows about 65.0% within 2 s | Humidity page showed 65.0% and ACTIVE; serial output also reported 65.0% | PASS |
| FT-03 | Change LDR lux control, select Light | Relative brightness percentage changes | Light page rendered 97%; serial output changed from 76% (ADC 980 at 501 lux) to 97% (ADC 130 at 13,183 lux) | PASS |
| FT-04 | Rotate encoder clockwise | Temperature -> Humidity -> Light -> Motion -> Temperature | During ACTIVE, the live run showed each page in order and returned to Temperature after the wrap; `Input: display page changed` appeared and the encoder produced CLK/DT pulses | PASS |
| FT-05 | Rotate encoder counterclockwise | Reverse sequence with wraparound | During ACTIVE, the live run showed Temperature -> Motion -> Light -> Humidity -> Temperature, including the reverse wrap; page-change logs appeared | PASS |
| FT-06 | Set DHT22 above 30 C | Buzzer sounds, OLED alarm indicator appears | At 33.1 C / 66.0%, a valid sample was logged and the OLED showed `ALARM`; the Wokwi buzzer activity icon was visible. The retained PB8 VCD measures about 500 Hz at 50% duty at 32 C. Independent physical acoustic level was not measured | PASS (Wokwi) |
| FT-07 | Return DHT22 to 24 C | Buzzer stops within next sensor sample | After changing the live DHT22 to 23.5 C / 65.0%, the next valid sample appeared and the recovery VCD showed PB8 low afterward | PASS |
| FT-08 | Trigger PIR | State log shows ACTIVE and OLED on | During Wokwi motion input, USART1 showed `Motion: detected` and `State: ACTIVE`; the OLED was lit | PASS |
| FT-09 | Wait 15 s after PIR output returns low | State log shows INACTIVE and OLED blanks | `State: INACTIVE` was observed after inactivity, with the OLED blank | PASS |
| FT-10 | Trigger PIR while INACTIVE | OLED restores and state log shows ACTIVE | After inactivity, PIR activation produced `Motion: detected` and `State: ACTIVE`; the OLED returned to its active display | PASS |

## Deliberate FreeRTOS fault experiments

These controlled faults were applied as reversible edits, built and run in Wokwi, then removed. The shipping firmware retains its periodic blocking and UART mutex. Results below describe observed behavior, not predictions.

| Experiment | Temporary change | What to observe | Actual observation | Status |
| --- | --- | --- | --- | --- |
| Remove blocking | Remove `vTaskDelayUntil()` in `MotionTask` | CPU load, lower-priority display/sensor latency, starvation | MotionTask heartbeats repeated continuously; the Wokwi speed indicator fell to 61-67%, and no sensor sample appeared during the observed interval | Observed |
| Raise priority | Set MotionTask priority to 4 and reduce its delay to 1 ms | Scheduling responsiveness of other tasks | The run reached 20 simulated seconds with recurring MotionTask heartbeats but no sensor sample; the simulator ran at about 90-95% speed | Observed starvation |
| Remove mutex | Bypass `serialMutex` in `boardLog` while MotionTask and SensorTask log | Interleaved UART lines | No garbled or interleaved line was visible in the short Wokwi capture; SensorTask and MotionTask messages remained complete. The race was not reproduced at this log rate | Inconclusive |

## Evidence record

1. [Full circuit](evidence/wokwi-full-circuit.png), [final production run](evidence/wokwi-production-final.png), [Temperature](evidence/wokwi-oled-28c-temperature.png), [Humidity](evidence/wokwi-oled-humidity.png), [Light](evidence/wokwi-oled-light.png), and [Motion](evidence/wokwi-oled-motion.png) screenshots record the circuit, stable task wakeups, and page rendering.
2. [Encoder trace](evidence/wokwi-input-components.vcd) contains PA1/PA2 quadrature changes in both directions. [Active encoder screenshot](evidence/wokwi-input-components.png) shows the `Input: display page changed` log while PIR is high. [Encoder pulse screenshot](evidence/wokwi-encoder-pulses.png) records the original pulse check. The 2026-09-30 live run's ordered page sequence is recorded in [the live verification note](evidence/wokwi-live-run-2026-09-30.md).
3. [PIR high/low trace](evidence/wokwi-pir-cycle.vcd) records the sensor output pulse returning low. The live Wokwi serial observation included `Motion: detected` and `State: ACTIVE`; the active encoder screenshot also shows a PIR-high heartbeat during page-change handling.
4. [Buzzer high-temperature waveform](evidence/wokwi-buzzer-alarm-on.vcd) and [test screenshot](evidence/wokwi-buzzer-pwm.png) document the 32 C PWM output; [recovery waveform](evidence/wokwi-buzzer-recovery.vcd) and [screenshot](evidence/wokwi-buzzer-recovery.png) document return to low after the 23.5 C sample. [Pre-fix no-PWM screenshot](evidence/wokwi-buzzer-no-pwm.png) is retained as a diagnostic baseline.
5. Temporary fault observations: [no-blocking run](evidence/experiment-no-blocking.png), [raised-priority run](evidence/experiment-high-priority.png), and [mutex-bypass run](evidence/experiment-no-mutex.png). Production blocking and UART synchronization were restored afterward.

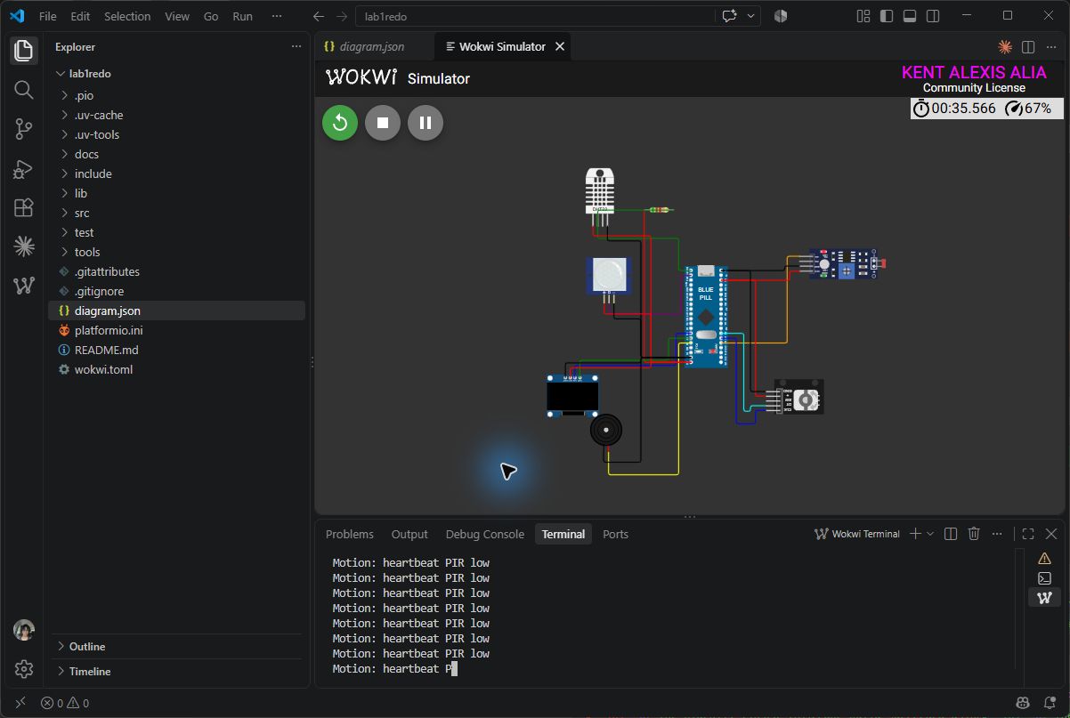
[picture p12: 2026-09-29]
docs/evidence/experiment-no-blocking.png

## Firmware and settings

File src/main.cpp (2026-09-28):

#include "board.h"
#include "rtos_objects.h"
#include "sensors.h"
#include "display.h"
#include "input.h"
#include "motion.h"
#include "alarm.h"
#include "system_state.h"
#include "task.h"

extern "C" void xPortSysTickHandler(void);
extern "C" void vPortSetupTimerInterrupt(void);

namespace {
// SysTick starts before the first task runs. Keep the ISR independent of the
// FreeRTOS API while the kernel is still initializing.
volatile bool schedulerStarted = false;

bool createTask(TaskFunction_t function, const char *name,
                uint16_t stackWords, UBaseType_t priority) {
  if (xTaskCreate(function, name, stackWords, nullptr, priority, nullptr) == pdPASS)
    return true;
  boardLog("Startup failed: cannot create ");
  boardLog(name);
  boardLog("\r\n");
  return false;
}
}

extern "C" void SysTick_Handler(void) {
  HAL_IncTick();
  if (schedulerStarted) xPortSysTickHandler();
}

// FreeRTOS calls this after it has created the idle task and marked the
// scheduler running, with interrupts masked. Start the RTOS tick only here;
// HAL_Init() had already enabled SysTick for HAL timeouts before this point.
extern "C" void vPortSetupTimerInterrupt(void) {
  SysTick->CTRL = 0U;
  SysTick->VAL = 0U;
  SysTick->LOAD = (configCPU_CLOCK_HZ / configTICK_RATE_HZ) - 1UL;
  schedulerStarted = true;
  SysTick->CTRL = SysTick_CTRL_CLKSOURCE_Msk |
                  SysTick_CTRL_TICKINT_Msk |
                  SysTick_CTRL_ENABLE_Msk;
}

extern "C" void vApplicationMallocFailedHook(void) { taskDISABLE_INTERRUPTS(); for (;;) {} }
extern "C" void vApplicationStackOverflowHook(TaskHandle_t, char *) {
  taskDISABLE_INTERRUPTS();
  for (;;) {}
}

extern "C" void HardFault_Handler(void) {
  static const char message[] = "HardFault\r\n";
  HAL_UART_Transmit(&huart1, reinterpret_cast<uint8_t *>(const_cast<char *>(message)),
                    sizeof(message) - 1, 100);
  for (;;) {}
}

void app_main() {
  if (!createRtosObjects()) for (;;) {}
  boardLog(SCB->VTOR == FLASH_BASE ? "Vector table: flash\r\n"
                                   : "Vector table: zero\r\n");
  boardLog("BCA182 FreeRTOS Multisensor System starting...\r\n");
  const bool created =
      createTask(MotionTask, "MotionTask", 160, 3) &&
      createTask(InputTask, "InputTask", 160, 3) &&
      createTask(StateTask, "StateTask", 192, 3) &&
      createTask(SensorTask, "SensorTask", 256, 2) &&
      createTask(AlarmTask, "AlarmTask", 192, 2) &&
      createTask(DisplayTask, "DisplayTask", 320, 1);
  if (!created) for (;;) {}
  boardLog("Tasks created; starting scheduler\r\n");
  vTaskStartScheduler();
  boardLog("Startup failed: scheduler returned\r\n");
  for (;;) {}
}

int main() {
  boardInit();
  app_main();
}

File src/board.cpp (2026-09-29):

#include "board.h"
#include "rtos_objects.h"
#include "task.h"
#include <cstring>

ADC_HandleTypeDef hadc1 = {};
I2C_HandleTypeDef hi2c1 = {};
UART_HandleTypeDef huart1 = {};
TIM_HandleTypeDef htim2 = {};
TIM_HandleTypeDef htim4 = {};

static void initClocks() {
  RCC_OscInitTypeDef oscillator = {};
  oscillator.OscillatorType = RCC_OSCILLATORTYPE_HSI;
  oscillator.HSIState = RCC_HSI_ON;
  oscillator.HSICalibrationValue = RCC_HSICALIBRATION_DEFAULT;
  oscillator.PLL.PLLState = RCC_PLL_ON;
  oscillator.PLL.PLLSource = RCC_PLLSOURCE_HSI_DIV2;
  oscillator.PLL.PLLMUL = RCC_PLL_MUL16;
  if (HAL_RCC_OscConfig(&oscillator) != HAL_OK) while (true) {}

  RCC_ClkInitTypeDef clocks = {};
  clocks.ClockType = RCC_CLOCKTYPE_HCLK | RCC_CLOCKTYPE_SYSCLK |
                     RCC_CLOCKTYPE_PCLK1 | RCC_CLOCKTYPE_PCLK2;
  clocks.SYSCLKSource = RCC_SYSCLKSOURCE_PLLCLK;
  clocks.AHBCLKDivider = RCC_SYSCLK_DIV1;
  clocks.APB1CLKDivider = RCC_HCLK_DIV2;
  clocks.APB2CLKDivider = RCC_HCLK_DIV1;
  if (HAL_RCC_ClockConfig(&clocks, FLASH_LATENCY_2) != HAL_OK) while (true) {}
}

void boardInit() {
  // Wokwi maps the firmware vectors at flash base but does not alias them at 0x0.
  SCB->VTOR = FLASH_BASE;
  __DSB();
  __ISB();
  HAL_Init();
  SCB->VTOR = FLASH_BASE;
  __DSB();
  __ISB();
  initClocks();
  CoreDebug->DEMCR |= CoreDebug_DEMCR_TRCENA_Msk;
  DWT->CYCCNT = 0;
  DWT->CTRL |= DWT_CTRL_CYCCNTENA_Msk;
  __HAL_RCC_GPIOA_CLK_ENABLE();
  __HAL_RCC_GPIOB_CLK_ENABLE();
  __HAL_RCC_AFIO_CLK_ENABLE();
  __HAL_RCC_ADC1_CLK_ENABLE();
  __HAL_RCC_I2C1_CLK_ENABLE();
  __HAL_RCC_USART1_CLK_ENABLE();
  __HAL_RCC_TIM2_CLK_ENABLE();
  __HAL_RCC_TIM4_CLK_ENABLE();

  GPIO_InitTypeDef gpio = {};
  gpio.Pin = DHT_PIN;
  gpio.Mode = GPIO_MODE_INPUT;
  gpio.Pull = GPIO_PULLUP;
  HAL_GPIO_Init(GPIOB, &gpio);
  gpio.Pin = BUZZER_PIN;
  gpio.Mode = GPIO_MODE_AF_PP;
  gpio.Pull = GPIO_NOPULL;
  gpio.Speed = GPIO_SPEED_FREQ_HIGH;
  HAL_GPIO_Init(GPIOB, &gpio);
  gpio.Pin = PIR_PIN;
  gpio.Mode = GPIO_MODE_INPUT;
  gpio.Pull = GPIO_PULLDOWN;
  HAL_GPIO_Init(GPIOB, &gpio);

  gpio.Pin = ENCODER_CLK_PIN;
  gpio.Mode = GPIO_MODE_IT_FALLING;
  gpio.Pull = GPIO_PULLUP;
  HAL_GPIO_Init(GPIOA, &gpio);
  gpio.Pin = ENCODER_DT_PIN;
  gpio.Mode = GPIO_MODE_INPUT;
  HAL_GPIO_Init(GPIOA, &gpio);
  HAL_NVIC_SetPriority(EXTI1_IRQn, 5, 0);
  HAL_NVIC_EnableIRQ(EXTI1_IRQn);

  gpio.Pin = GPIO_PIN_6 | GPIO_PIN_7;
  gpio.Mode = GPIO_MODE_AF_OD;
  gpio.Pull = GPIO_PULLUP;
  gpio.Speed = GPIO_SPEED_FREQ_HIGH;
  HAL_GPIO_Init(GPIOB, &gpio);
  gpio.Pin = GPIO_PIN_9;
  gpio.Mode = GPIO_MODE_AF_PP;
  HAL_GPIO_Init(GPIOA, &gpio);
  gpio.Pin = GPIO_PIN_0;
  gpio.Mode = GPIO_MODE_ANALOG;
  HAL_GPIO_Init(GPIOA, &gpio);

  huart1.Instance = USART1;
  huart1.Init.BaudRate = 115200;
  huart1.Init.WordLength = UART_WORDLENGTH_8B;
  huart1.Init.StopBits = UART_STOPBITS_1;
  huart1.Init.Parity = UART_PARITY_NONE;
  huart1.Init.Mode = UART_MODE_TX;
  huart1.Init.HwFlowCtl = UART_HWCONTROL_NONE;
  huart1.Init.OverSampling = UART_OVERSAMPLING_16;
  if (HAL_UART_Init(&huart1) != HAL_OK) while (true) {}

  hi2c1.Instance = I2C1;
  hi2c1.Init.ClockSpeed = 100000;
  hi2c1.Init.DutyCycle = I2C_DUTYCYCLE_2;
  hi2c1.Init.OwnAddress1 = 0;
  hi2c1.Init.AddressingMode = I2C_ADDRESSINGMODE_7BIT;
  hi2c1.Init.DualAddressMode = I2C_DUALADDRESS_DISABLE;
  hi2c1.Init.OwnAddress2 = 0;
  hi2c1.Init.GeneralCallMode = I2C_GENERALCALL_DISABLE;
  hi2c1.Init.NoStretchMode = I2C_NOSTRETCH_DISABLE;
  if (HAL_I2C_Init(&hi2c1) != HAL_OK) while (true) {}

  hadc1.Instance = ADC1;
  hadc1.Init.ScanConvMode = ADC_SCAN_DISABLE;
  hadc1.Init.ContinuousConvMode = DISABLE;
  hadc1.Init.DiscontinuousConvMode = DISABLE;
  hadc1.Init.ExternalTrigConv = ADC_SOFTWARE_START;
  hadc1.Init.DataAlign = ADC_DATAALIGN_RIGHT;
  hadc1.Init.NbrOfConversion = 1;
  if (HAL_ADC_Init(&hadc1) != HAL_OK) while (true) {}
  ADC_ChannelConfTypeDef channel = {};
  channel.Channel = ADC_CHANNEL_0;
  channel.Rank = ADC_REGULAR_RANK_1;
  channel.SamplingTime = ADC_SAMPLETIME_71CYCLES_5;
  if (HAL_ADC_ConfigChannel(&hadc1, &channel) != HAL_OK) while (true) {}
  HAL_ADCEx_Calibration_Start(&hadc1);

  htim2.Instance = TIM2;
  htim2.Init.Prescaler = (SystemCoreClock / 1000000U) - 1U;
  htim2.Init.CounterMode = TIM_COUNTERMODE_UP;
  htim2.Init.Period = 0xffffU;
  htim2.Init.ClockDivision = TIM_CLOCKDIVISION_DIV1;
  if (HAL_TIM_Base_Init(&htim2) != HAL_OK || HAL_TIM_Base_Start(&htim2) != HAL_OK)
    while (true) {}

  htim4.Instance = TIM4;
  htim4.Init.Prescaler = (SystemCoreClock / 1000000U) - 1U;
  htim4.Init.CounterMode = TIM_COUNTERMODE_UP;
  htim4.Init.Period = 1999U;
  htim4.Init.ClockDivision = TIM_CLOCKDIVISION_DIV1;
  if (HAL_TIM_PWM_Init(&htim4) != HAL_OK) while (true) {}
  TIM_OC_InitTypeDef pulse = {};
  pulse.OCMode = TIM_OCMODE_PWM1;
  pulse.Pulse = 1000U;
  pulse.OCPolarity = TIM_OCPOLARITY_HIGH;
  pulse.OCFastMode = TIM_OCFAST_DISABLE;
  if (HAL_TIM_PWM_ConfigChannel(&htim4, &pulse, TIM_CHANNEL_3) != HAL_OK) while (true) {}
}
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

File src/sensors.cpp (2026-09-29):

#include "sensors.h"
#include "board.h"
#include "rtos_objects.h"
#include "logic.h"
#include "task.h"
#include <cstdio>

static void driveDhtLow() {
  GPIO_InitTypeDef gpio = {};
  gpio.Pin = DHT_PIN;
  gpio.Mode = GPIO_MODE_OUTPUT_OD;
  gpio.Pull = GPIO_NOPULL;
  gpio.Speed = GPIO_SPEED_FREQ_HIGH;
  HAL_GPIO_Init(GPIOB, &gpio);
  HAL_GPIO_WritePin(GPIOB, DHT_PIN, GPIO_PIN_RESET);
}

static void releaseDhtBus() {
  GPIO_InitTypeDef gpio = {};
  gpio.Pin = DHT_PIN;
  gpio.Mode = GPIO_MODE_INPUT;
  gpio.Pull = GPIO_PULLUP;
  HAL_GPIO_Init(GPIOB, &gpio);
}

static bool waitForPin(GPIO_PinState level, uint32_t timeoutUs) {
  const uint32_t start = boardMicros();
  uint32_t spins = 0;
  const uint32_t spinLimit = timeoutUs * 64U;
  while (HAL_GPIO_ReadPin(GPIOB, DHT_PIN) != level) {
    if (static_cast<uint16_t>(boardMicros() - start) > timeoutUs ||
        ++spins >= spinLimit) return false;
  }
  return true;
}

static bool readDht(float &temperature, float &humidity, const char *&failure) {
  uint8_t bytes[5] = {};
  uint8_t decodedOnes = 0;
  uint16_t shortestPulse = UINT16_MAX;
  uint16_t longestPulse = 0;
  driveDhtLow();
  vTaskDelay(pdMS_TO_TICKS(2));
  boardLog("Sensor: DHT start delay finished\r\n");
  taskENTER_CRITICAL();
  releaseDhtBus();
  failure = "response-low";
  bool ok = waitForPin(GPIO_PIN_RESET, 120);
  if (ok) {
    failure = "response-high";
    ok = waitForPin(GPIO_PIN_SET, 120);
  }
  if (ok) {
    failure = "first-data-low";
    ok = waitForPin(GPIO_PIN_RESET, 120);
  }
  for (int bit = 0; bit < 40 && ok; ++bit) {
    failure = "data-bit-low";
    ok = waitForPin(GPIO_PIN_SET, 90);
    if (!ok) break;
    const uint32_t highStart = boardMicros();
    // Sample between the AM2302's 26-28 us zero pulse and ~70 us one pulse.
    // Sampling at a fixed midpoint avoids classifying bits from two polled
    // edge timestamps, whose loop jitter can skew a measured pulse width.
    uint32_t sampleSpins = 0;
    while (static_cast<uint32_t>(boardMicros() - highStart) < 40U) {
      if (++sampleSpins >= 40U * 64U) {
        failure = "data-bit-sample";
        ok = false;
        break;
      }
    }
    if (!ok) break;
    const bool decodedOne = HAL_GPIO_ReadPin(GPIOB, DHT_PIN) == GPIO_PIN_SET;
    failure = "data-bit-high";
    ok = waitForPin(GPIO_PIN_RESET, 100);
    if (!ok) break;
    const uint16_t pulseWidth = static_cast<uint16_t>(boardMicros() - highStart);
    if (pulseWidth < shortestPulse) shortestPulse = pulseWidth;
    if (pulseWidth > longestPulse) longestPulse = pulseWidth;
    if (decodedOne) ++decodedOnes;
    bytes[bit / 8] = static_cast<uint8_t>((bytes[bit / 8] << 1) | (decodedOne ? 1U : 0U));
  }
  taskEXIT_CRITICAL();
  if (!ok) return false;
  failure = "checksum";
  const uint8_t checksum = static_cast<uint8_t>(bytes[0] + bytes[1] + bytes[2] + bytes[3]);
  if (checksum != bytes[4]) {
    char line[128];
    std::snprintf(line, sizeof(line),
                  "Sensor: DHT checksum mismatch sum %02X got %02X, data %02X %02X %02X %02X, bits %u, pulse %u-%u us\r\n",
                  static_cast<unsigned int>(checksum), static_cast<unsigned int>(bytes[4]),
                  static_cast<unsigned int>(bytes[0]), static_cast<unsigned int>(bytes[1]),
                  static_cast<unsigned int>(bytes[2]), static_cast<unsigned int>(bytes[3]),
                  static_cast<unsigned int>(decodedOnes), static_cast<unsigned int>(shortestPulse),
                  static_cast<unsigned int>(longestPulse));
    boardLog(line);
    return false;
  }
  const uint16_t rawHumidity = static_cast<uint16_t>((bytes[0] << 8) | bytes[1]);
  const uint16_t rawTemperature = static_cast<uint16_t>(((bytes[2] & 0x7fU) << 8) | bytes[3]);
  humidity = rawHumidity / 10.0f;
  temperature = rawTemperature / 10.0f;
  if (bytes[2] & 0x80U) temperature = -temperature;
  failure = "";
  return true;
}

void SensorTask(void *) {
  boardLog("Sensor: waiting for DHT22 power-up\r\n");
  vTaskDelay(pdMS_TO_TICKS(2000));
  TickType_t lastWake = xTaskGetTickCount();
  for (;;) {
    SensorData data = {};
    const char *dhtFailure = "unknown";
    char line[96];
    boardLog("Sensor: sampling DHT22\r\n");
    data.dhtValid = readDht(data.temperature, data.humidity, dhtFailure);
    if (data.dhtValid) boardLog("Sensor: DHT22 read complete\r\n");
    const uint16_t lightAdc = boardReadLightAdc();
    data.lightLevel = lightPercentFromAdc(lightAdc);
    xQueueOverwrite(displaySensorQueue, &data);
    xQueueOverwrite(alarmSensorQueue, &data);
    if (data.dhtValid) {
      const int temp10 = static_cast<int>(data.temperature * 10.0f);
      const int hum10 = static_cast<int>(data.humidity * 10.0f);
      std::snprintf(line, sizeof(line), "Sensor: %d.%d C, %d.%d %%\r\n",
                    temp10 / 10, temp10 % 10, hum10 / 10, hum10 % 10);
    } else {
      std::snprintf(line, sizeof(line), "Sensor: DHT failure at %s\r\n", dhtFailure);
    }
    boardLog(line);
    std::snprintf(line, sizeof(line), "Sensor: light %d %% ADC %u\r\n", data.lightLevel,
                  static_cast<unsigned int>(lightAdc));
    boardLog(line);
    vTaskDelayUntil(&lastWake, pdMS_TO_TICKS(2000));
  }
}

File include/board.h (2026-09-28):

#pragma once

#include "stm32f1xx_hal.h"

extern ADC_HandleTypeDef hadc1;
extern I2C_HandleTypeDef hi2c1;
extern UART_HandleTypeDef huart1;
extern TIM_HandleTypeDef htim2;
extern TIM_HandleTypeDef htim4;

void boardInit();
uint16_t boardReadLightAdc();
uint32_t boardMicros();
void boardBuzzer(bool enabled);
void boardLog(const char *message);

constexpr uint16_t DHT_PIN = GPIO_PIN_12;
constexpr uint16_t PIR_PIN = GPIO_PIN_13;
constexpr uint16_t ENCODER_CLK_PIN = GPIO_PIN_1;
constexpr uint16_t ENCODER_DT_PIN = GPIO_PIN_2;
constexpr uint16_t BUZZER_PIN = GPIO_PIN_8;

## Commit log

2026-09-28 Implement STM32Cube FreeRTOS room monitor and logic tests
2026-09-29 Fix DHT22 bus release and pull-up
    [board.cpp, sensors.cpp]
2026-09-29 Record Wokwi sensor verification evidence
2026-09-29 Fix PB8 buzzer GPIO output mode
    [board.cpp]
2026-09-29 Complete Wokwi encoder and alarm verification
2026-09-30 Add Fritzing multisensor schematic
    [BCA182-Multisensor-Schematic.fzz]
2026-09-30 Add ground symbol to Fritzing schematic
    [BCA182-Multisensor-Schematic.fzz]
